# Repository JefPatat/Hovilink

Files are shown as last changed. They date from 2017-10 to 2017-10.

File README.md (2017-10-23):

# Hovilink
**Ho**mebrew **vi**essmann Opto**link** is a serial to network interface built to connect a Viessmann Vitotronic heating control to the network or internet.

# Motivation
I have been using a bulky self built interface based on information available openv together with PC software. This setup was not handy and serious overkill for the purpose. I want to enable myself to communicate with my heater over the network. To keep this flexible the harware is split up in an interface module which translates the optical signals to RS232. This RS232 can then be connected with various other interfaces.

# Limitations
The initial setup of this repository only aims to opensource my personal project and is limited to my personal heater and setup. I'm open to input of the community to expand on this.

# Hardware
The Vitotronic uses an optocoupler to communicate. It uses its status LEDs for this. The left, red, LED functions as an error indicator and at the same time as an infrared receiver. The right, green, LED as an operation indicator an infrared transmitter. Further details will be added to the wiki.

# Software
TBD

# Credits
https://openv.wikispaces.com

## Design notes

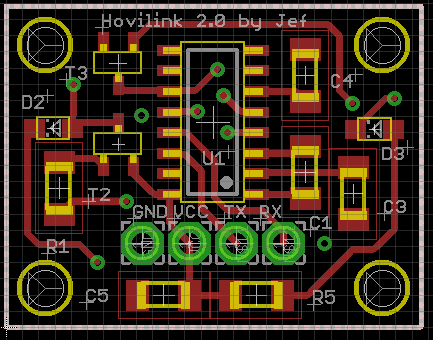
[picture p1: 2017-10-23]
Hardware/Hovilink 2.0/Top.PNG

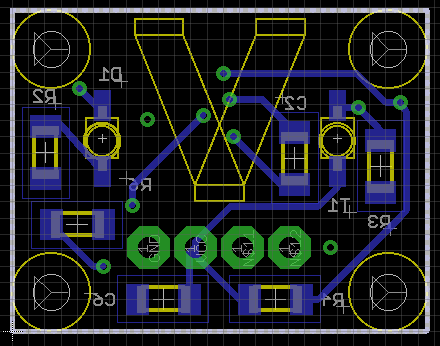
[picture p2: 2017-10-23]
Hardware/Hovilink 2.0/Bottom.PNG

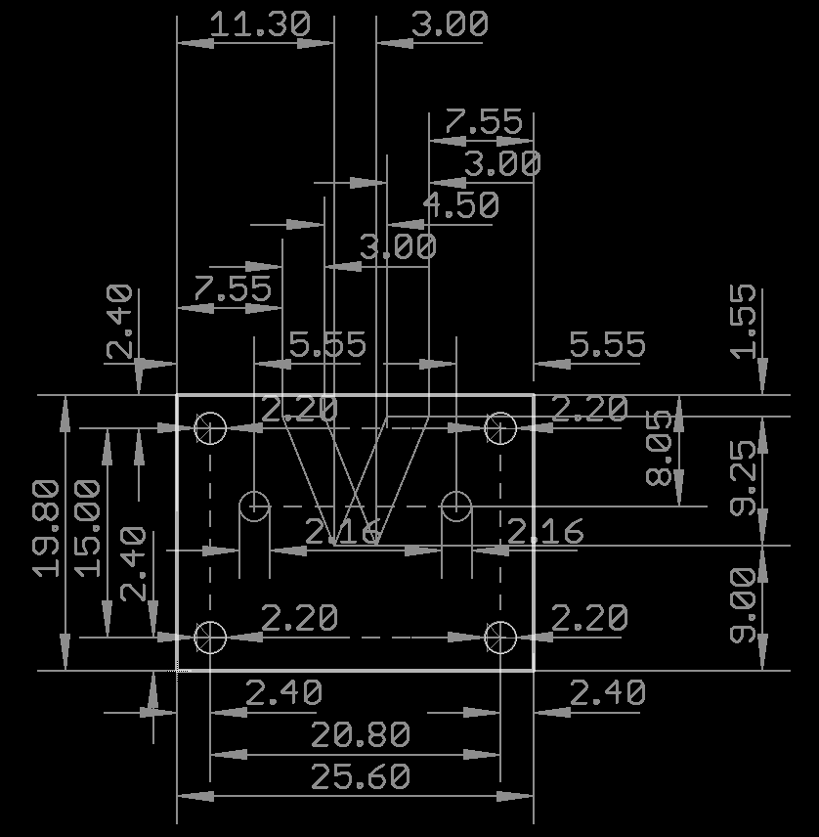
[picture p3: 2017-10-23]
Hardware/Hovilink 2.0/Dimensions.png

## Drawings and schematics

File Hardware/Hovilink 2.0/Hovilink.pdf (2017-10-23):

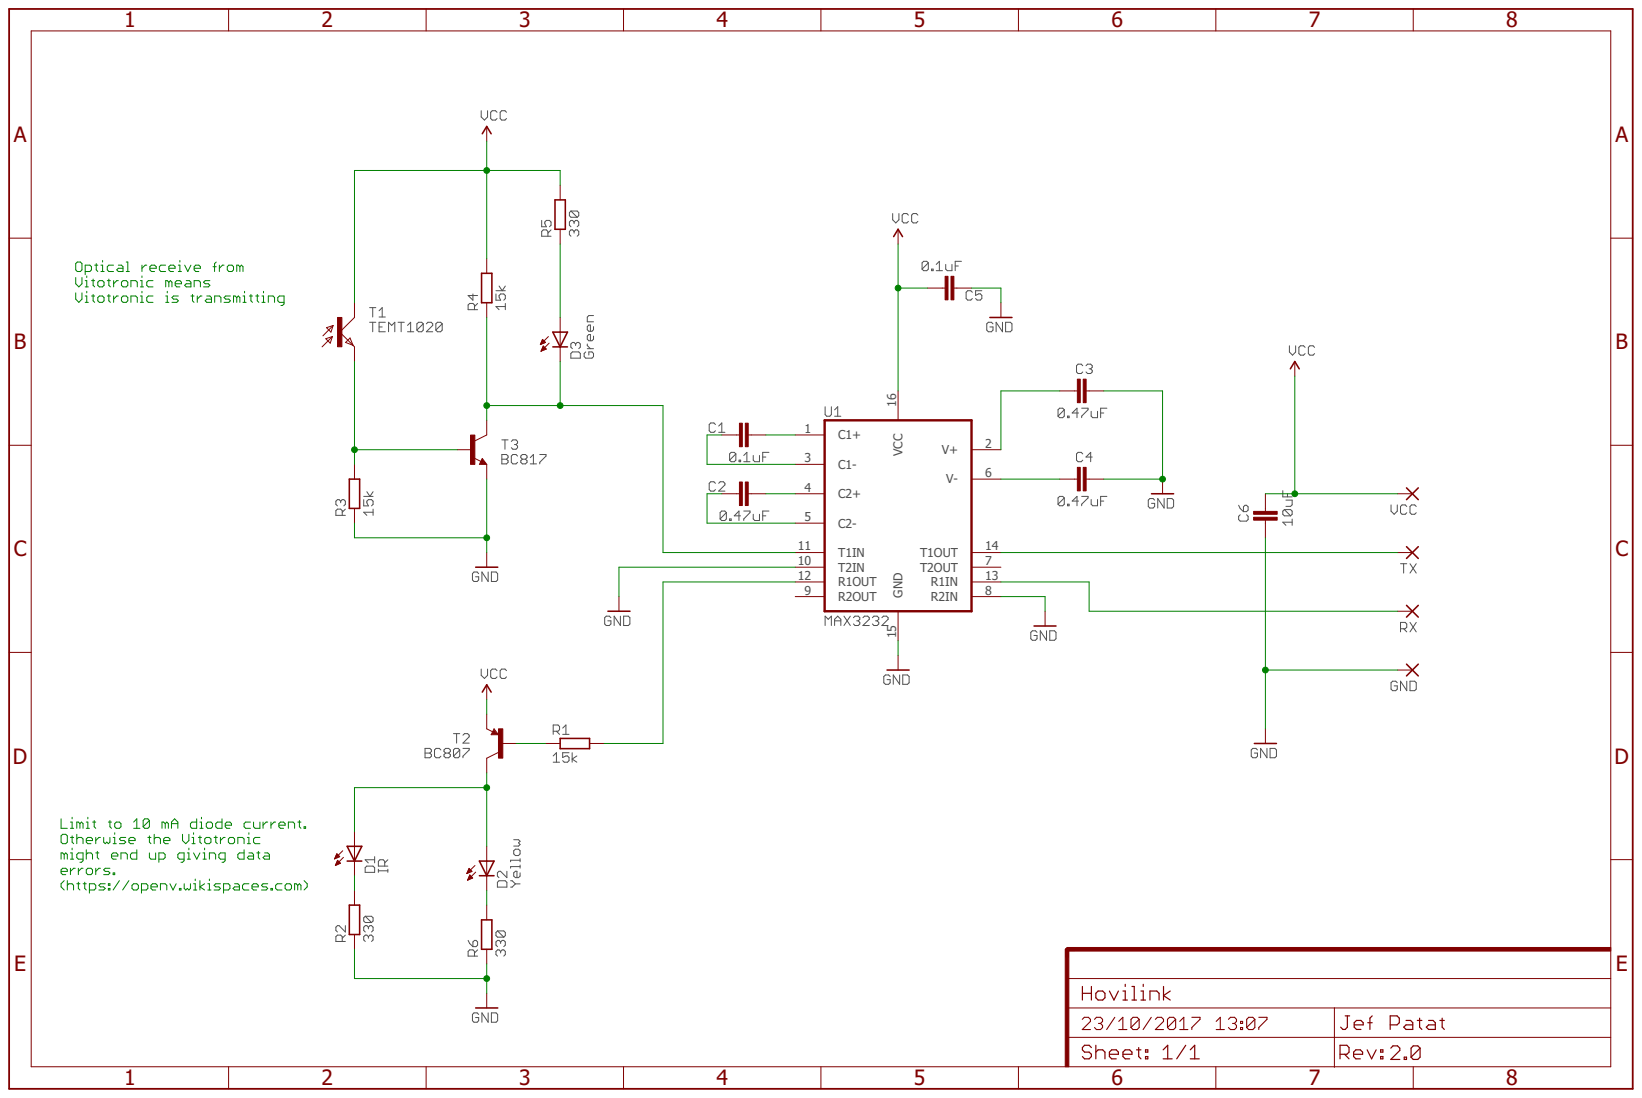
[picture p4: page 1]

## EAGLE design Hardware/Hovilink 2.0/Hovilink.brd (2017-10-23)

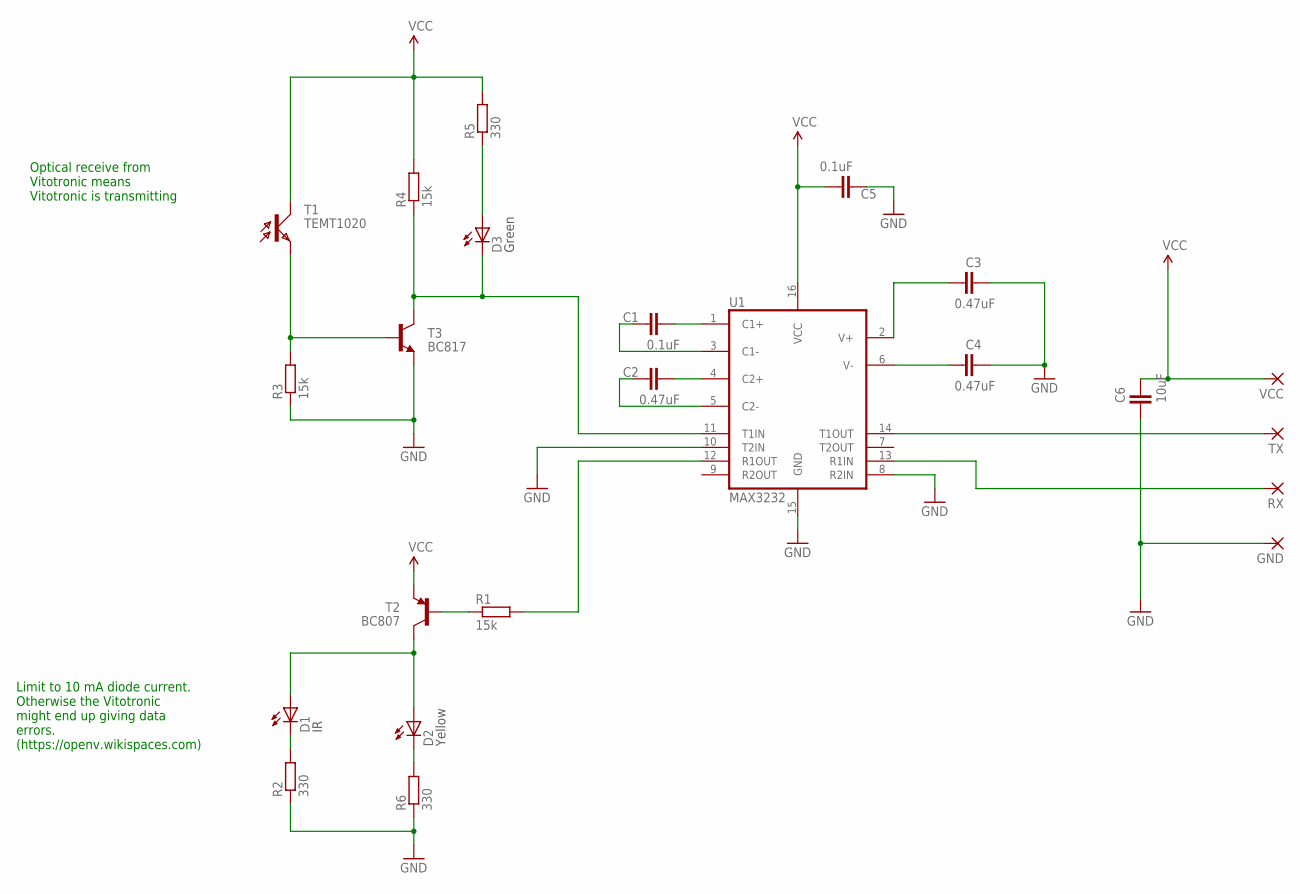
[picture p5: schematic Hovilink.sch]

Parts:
C1, C5: 0.1uF; 1206
C2, C3, C4: 0.47uF; 1206
C6: 10uF; 1206
D1: TSMF1020
D2: KP-2012SYCK; KNIGHTBRIGHT_2.0X1.25_SMD_LED
D3: KP-2012CGCK; KNIGHTBRIGHT_2.0X1.25_SMD_LED
GND: WIREPAD_2,54/1,3
R1, R3, R4: 15k; 1206
R2, R5, R6: 330; 1206
RX: WIREPAD_2,54/1,3
T1: TEMT1020
T2: BC807; SOT23_3
T3: BC817; SOT23_3
TX: WIREPAD_2,54/1,3
U1: MAX3232; SOIC16
VCC: WIREPAD_2,54/1,3

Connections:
GND: C3.2, C4.2, C5.1, C6.1, GND.1, R2.1, R3.1, R6.1, T3.2 (E), U1.8 (R2IN), U1.10 (T2IN), U1.15 (GND)
unnamed: C4.1, U1.6 (V-)
unnamed: C3.1, U1.2 (V+)
unnamed: R1.1, T2.1 (B)
unnamed: C1.2, U1.1 (C1+)
unnamed: C1.1, U1.3 (C1-)
unnamed: C2.2, U1.4 (C2+)
unnamed: C2.1, U1.5 (C2-)
unnamed: D1.P$1 (C), R2.2
unnamed: D1.P$2 (A), D2.P$1 (A), T2.3 (C)
unnamed: R1.2, U1.12 (R1OUT)
unnamed: TX.1, U1.14 (T1OUT)
unnamed: RX.1, U1.13 (R1IN)
unnamed: R3.2, T1.P$2 (E), T3.1 (B)
unnamed: D3.P$2 (C), R4.1, T3.3 (C), U1.11 (T1IN)
unnamed: D2.P$2 (C), R6.2
unnamed: D3.P$1 (A), R5.1
VCC: C5.2, C6.2, R4.2, R5.2, T1.P$1 (C), T2.2 (E), U1.16 (VCC), VCC.1

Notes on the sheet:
Optical receive from Vitotronic means Vitotronic is transmitting
Limit to 10 mA diode current. Otherwise the Vitotronic might end up giving data errors. (https://openv.wikispaces.com)

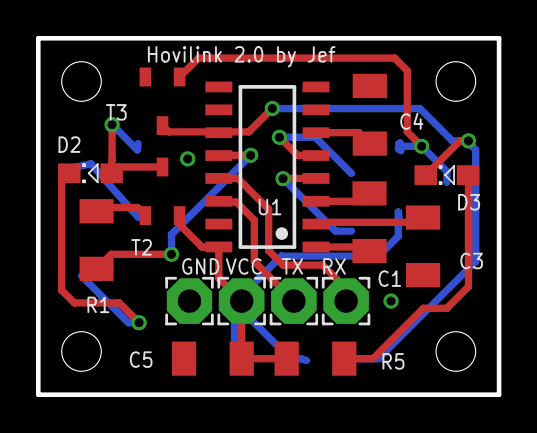
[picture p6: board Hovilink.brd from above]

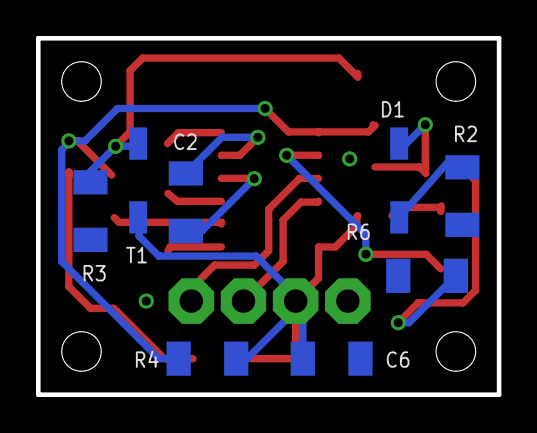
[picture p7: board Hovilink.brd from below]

Board: 2 copper layers, 25.6 x 19.8 mm, 23 parts (8 on the bottom side), 18 nets.

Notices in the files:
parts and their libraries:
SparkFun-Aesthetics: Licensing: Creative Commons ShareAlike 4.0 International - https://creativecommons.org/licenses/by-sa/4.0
